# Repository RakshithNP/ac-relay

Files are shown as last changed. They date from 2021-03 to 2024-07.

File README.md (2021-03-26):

View this project on [CADLAB.io](https://cadlab.io/project/24087). 

# AC Relay


It is a relay controlled by an ESP8266 and a push button. It is powered by the main AC.

### Firmwares

#### Test

This firmware allows you to test the hardware if needed. It will change the relay status each 400 millisenconds when the button is pressed and it will send the push button status via serial communication.

#### AdafruitIO

This firmware is based in the Adafruit example for comumnicate with its MQTT broker called AdafruitIO. You can see more in <a href="https://io.adafruit.com">io.adafruit.com</a>

In order to use it you should set:

- Your WiFi setting
- You Adafruit user name
- API Key from Adafruit IO
- The MQTT feed which will be used in Adafruit IO

#### MQTT

This firmware allows you to communicate with a MQTT broker. For example, you can install your own MQTT broker in a Raspberry Pi.

This is the actual firmware that I am using at home with this circuit, and it is prepared for being working 24/7. It does:

- Recovery after a power failure.
- Wake up message
- Reconnect message
- Serial debug
- WiFi reconnect if the signal is lost
- MQTT Broker reconnect if the signal is lost

### For future revisions

- `LED`: LED as IO instead of Power LED
- `ESP8266`: ESP8266 as SoC instead of the ESP8266-12E module
- `UPS`: Uninterrupted Power System. Cesar Fernández idea
- `Capacitive button`: A capacitive external button that acts as the push button

***

<br /><span xmlns:dct="http://purl.org/dc/terms/" property="dct:title">Home AC relay</span> by <span xmlns:cc="http://creativecommons.org/ns#" property="cc:attributionName">Enrique Gómez</span> licensed by <a rel="license" href="http://creativecommons.org/licenses/by-sa/4.0/">Creative Commons Attribution-ShareAlike 4.0 International License</a>.<br /><br />

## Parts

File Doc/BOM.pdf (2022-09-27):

# AC Relay – Bill of Materials

Rev.: 4 | Made By: Enrique Gómez erify By: | Date: 27/09/22
Item Designator Description | Ordering code | Suplier | Manufacturer | Footprint Qty. Ordering code 2 | Suplier 2 | Value
1 | U2 | ESP8266 | - | - | - | - | 1 | - | - | -
2 | U3 | Bloque AC/DC | HLK-PM01 | - | Hi-link | | 1 | HLK-PM01 | HLK-PM01 | 5V output
3 | Q1 | Transistor | 512-FDT86246L | Mouser | On Semiconductor | SOT-223-4 | 1 | FDT86246L | On Semiconductor
4 | D1 | Diodo | 512-RGF1B | Mouser | On Semiconductor | DO-214AC | 1 | RGF1B | On Semiconductor | Vf = 1000v; If = 1A
5 | K1 | Relé | 655-1-2071556-1 | Mouser | TE Connectivity | - | 1 | 1-2071556-1 | TE Connectivity
6 | SW1 | Pulsador | 611-PTS647SN70SMTR2L Mouser | C&K | 4,5 x 4,5 mm 1 | C&K | SPST
7 | R1,R2,R3 | Resistencia | 279-CRGP0603F10K | Mouser | TE Connectivity | 0603 | 3 | CRGP0603F10K | TE Connectivity | 10k
8 | D2 | LED verde | 710-150060VS75000 | Mouser | Wurth Electronics | 0603 | 1 | 150060VS75000 | Wurth Electronics | Vf = 2v; If = 20 mA
9 | R4 | Resistencia | 754-RR0816Q-82R5D89R Mouser | Susumu | 0603 | 1 | RR0816Q-82R5-D-89R Susumu | 82,5 Ohm
10 | U1 | | 755-BU33SD5WG-TR | Mouser | ROHM Semiconductor | SOT-23-5 | 1 | BU33SD5WG-TR | | 3,3V
11 | C1, C2 | Condensador | 77-VJ0603G474KXQPBC | Mouser | Vishay | 0603 | 2 | | Vishay | 470nf
12 | J2 | Header pins | - | - | - | - | 1 | - | - | 01 x 06 pin
13 | J1,J3 | Screw Terminal 651-1985920 | Mouser | Phoenix Contact | 2 x 5 mm | 2 | 1985920 | Phoenix Contact | I = 16A; V = 320v

PTS647SN70SMTR2LF
S

Regulador
voltaje

ROHM
Semiconductor VJ0603G474KXQPW1

BC

### Notas

:

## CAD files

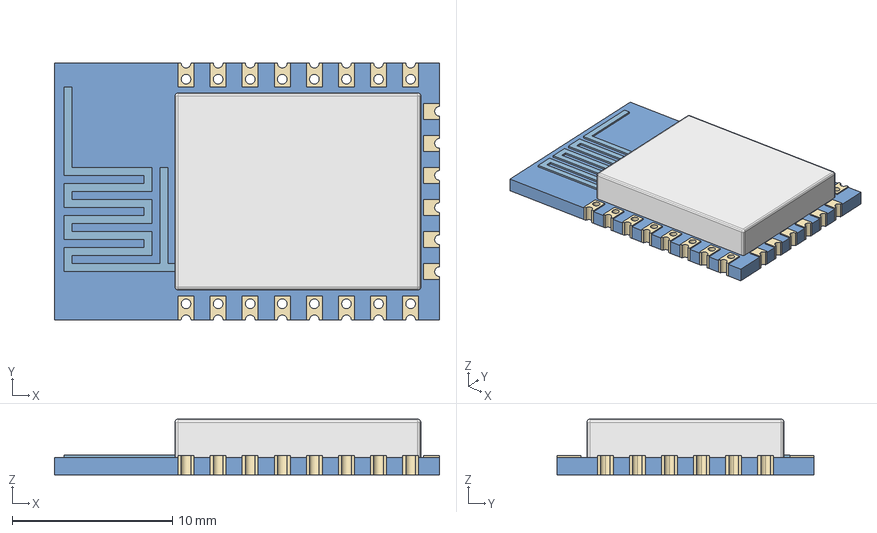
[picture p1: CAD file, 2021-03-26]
KiCad/AC Relay/3dpackages/ESP8266.fcstd
24.0 x 16.0 x 3.48 mm

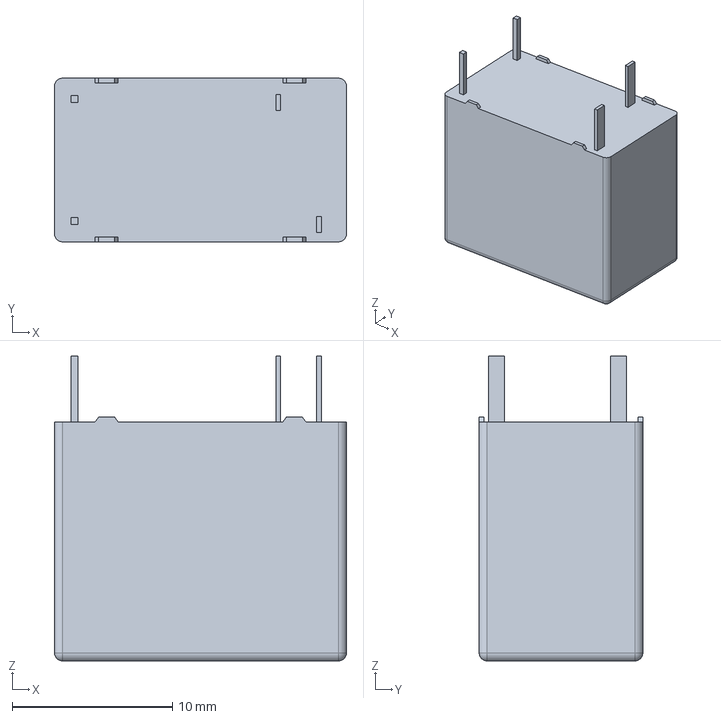
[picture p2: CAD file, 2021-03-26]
KiCad/AC Relay/3dpackages/c-1461492-2-d4-3d.stp
18.2 x 10.2 x 19.0 mm

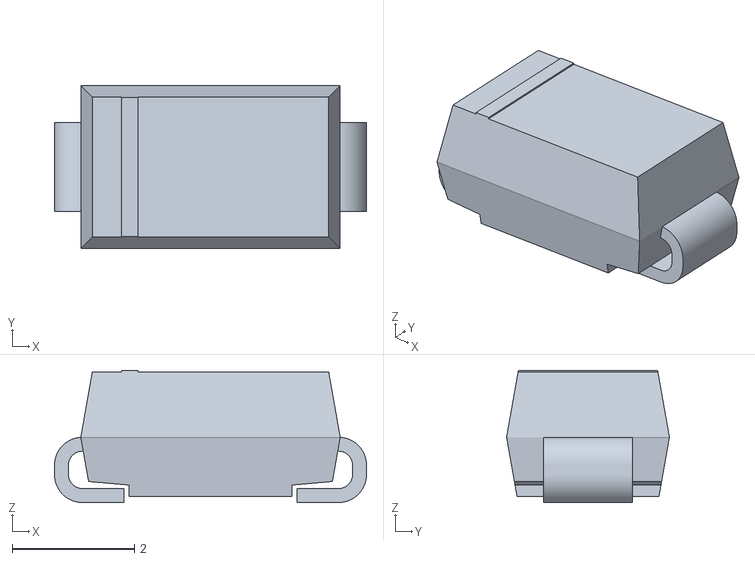
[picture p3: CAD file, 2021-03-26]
KiCad/AC Relay/3dpackages/AB2_DO-214AC_WINGS3D.stl
5.11 x 2.66 x 2.16

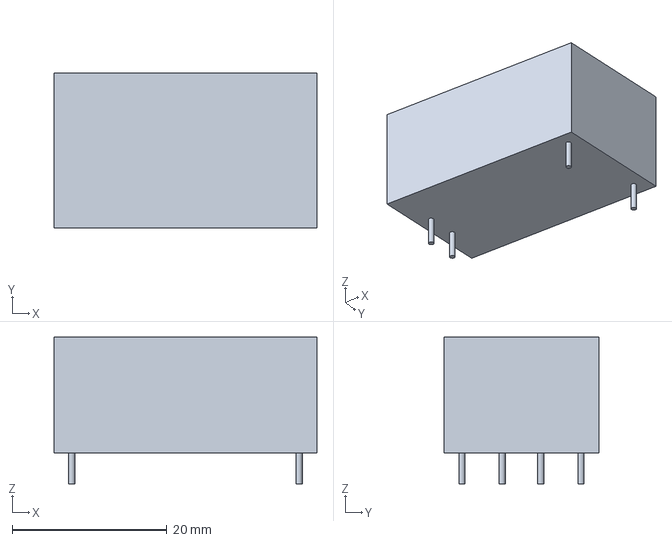
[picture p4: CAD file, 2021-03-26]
KiCad/AC Relay/3dpackages/AC-DC_HLK-PM01.fcstd
34.0 x 20.0 x 19.0 mm

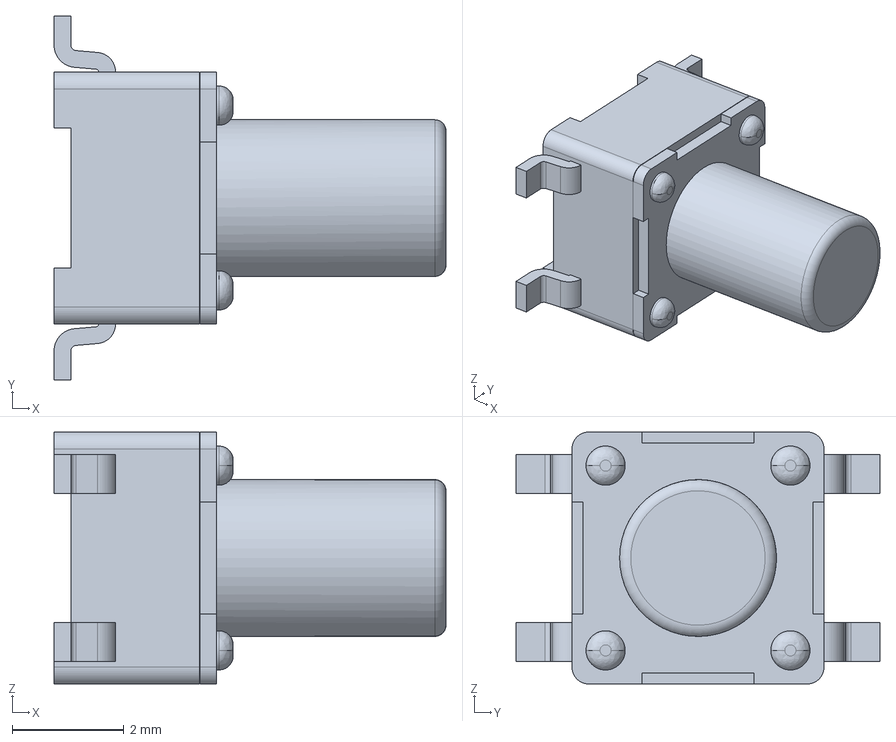
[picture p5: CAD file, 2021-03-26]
KiCad/AC Relay/3dpackages/PTS647SN70SMTR2LFS.stp
7.00 x 6.50 x 4.50 mm

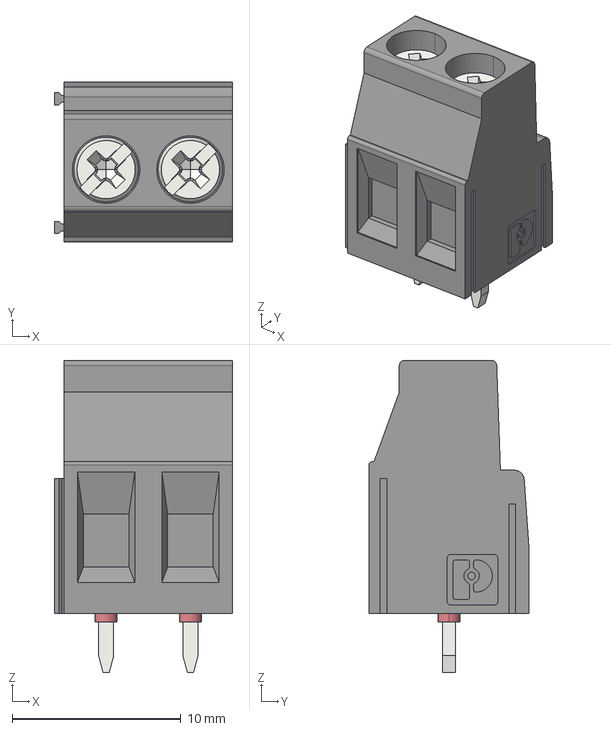
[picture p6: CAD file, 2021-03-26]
KiCad/AC Relay/3dpackages/pxc_1985920_00_MKDSN-2-5-2-HT-BK_3D.stp
10.6 x 9.50 x 18.5 mm
Bohrloch x 2
mkdsn_2.5-2-ht_bk

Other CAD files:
KiCad/AC Relay/3dpackages/ESP8266-12E.stp

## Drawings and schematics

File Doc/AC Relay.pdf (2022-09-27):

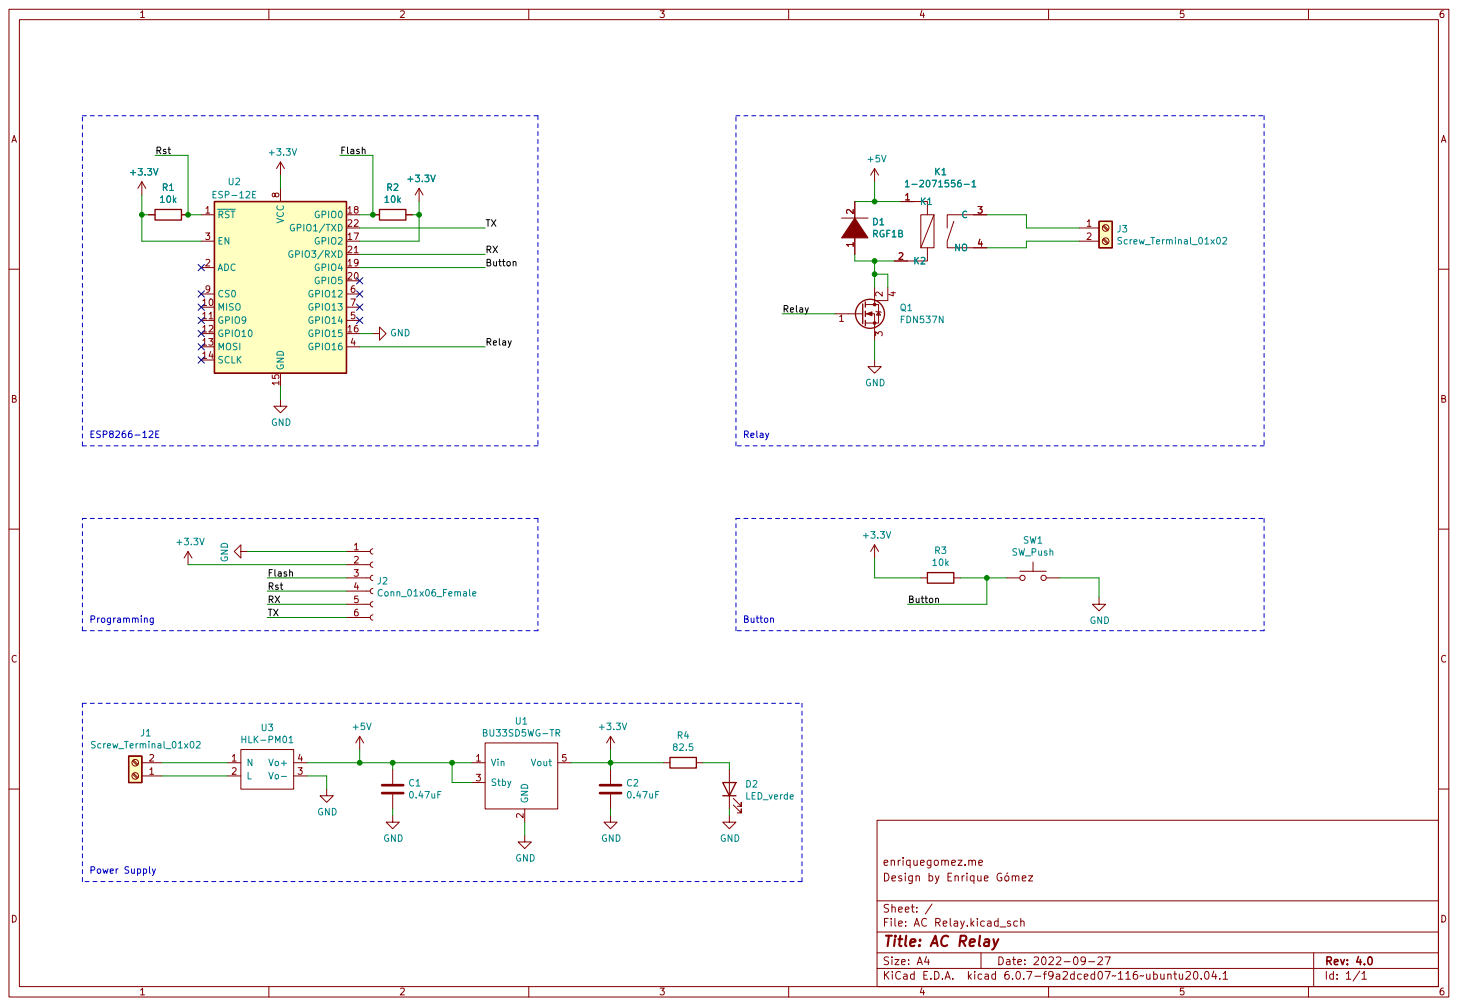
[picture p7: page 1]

enriquegomez.me
File: AC Relay.kicad_sch Sheet: / þÿDesign by Enrique Gómez

Id: 1/1 Title: AC Relay

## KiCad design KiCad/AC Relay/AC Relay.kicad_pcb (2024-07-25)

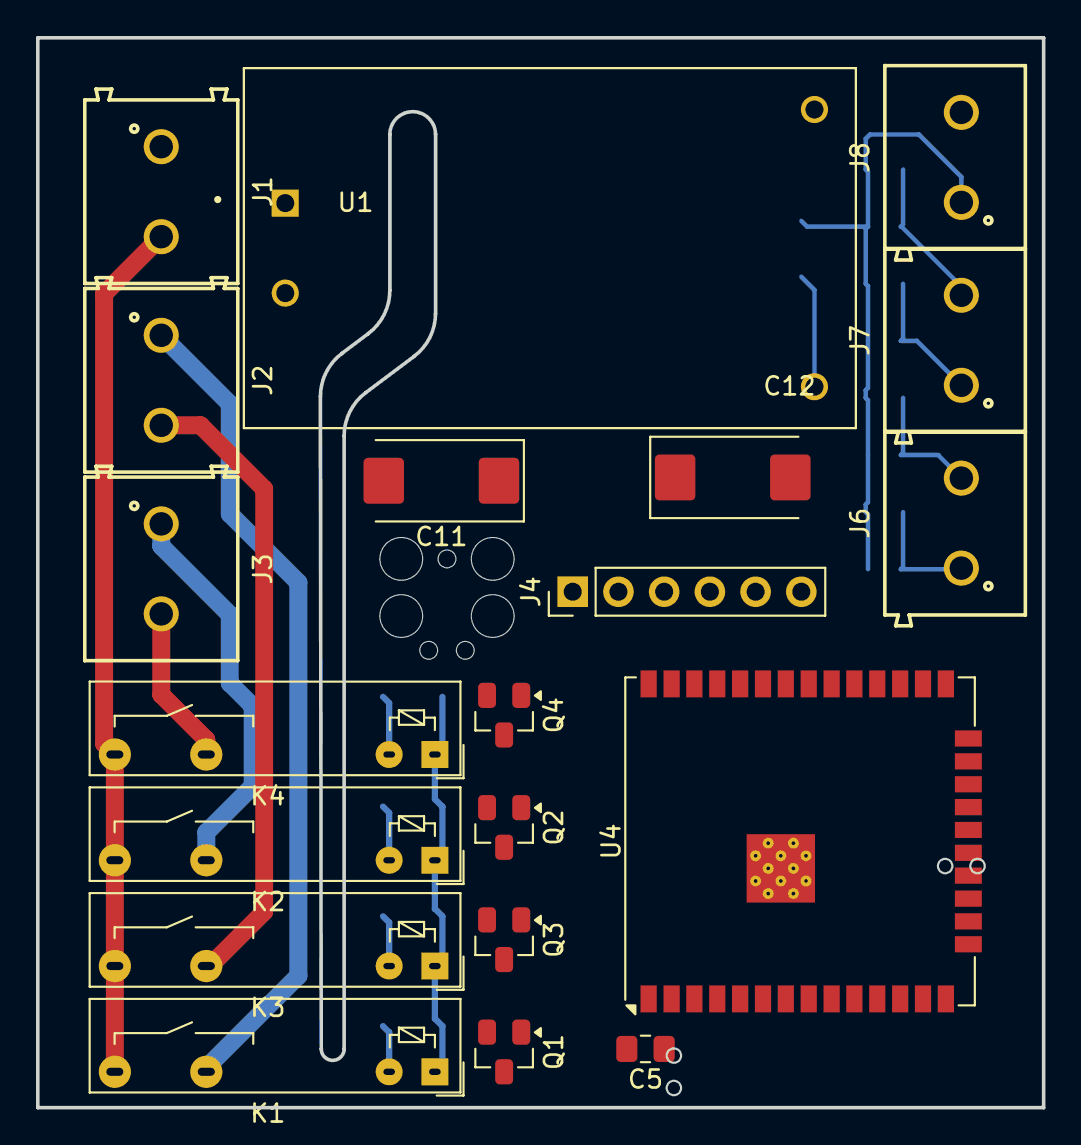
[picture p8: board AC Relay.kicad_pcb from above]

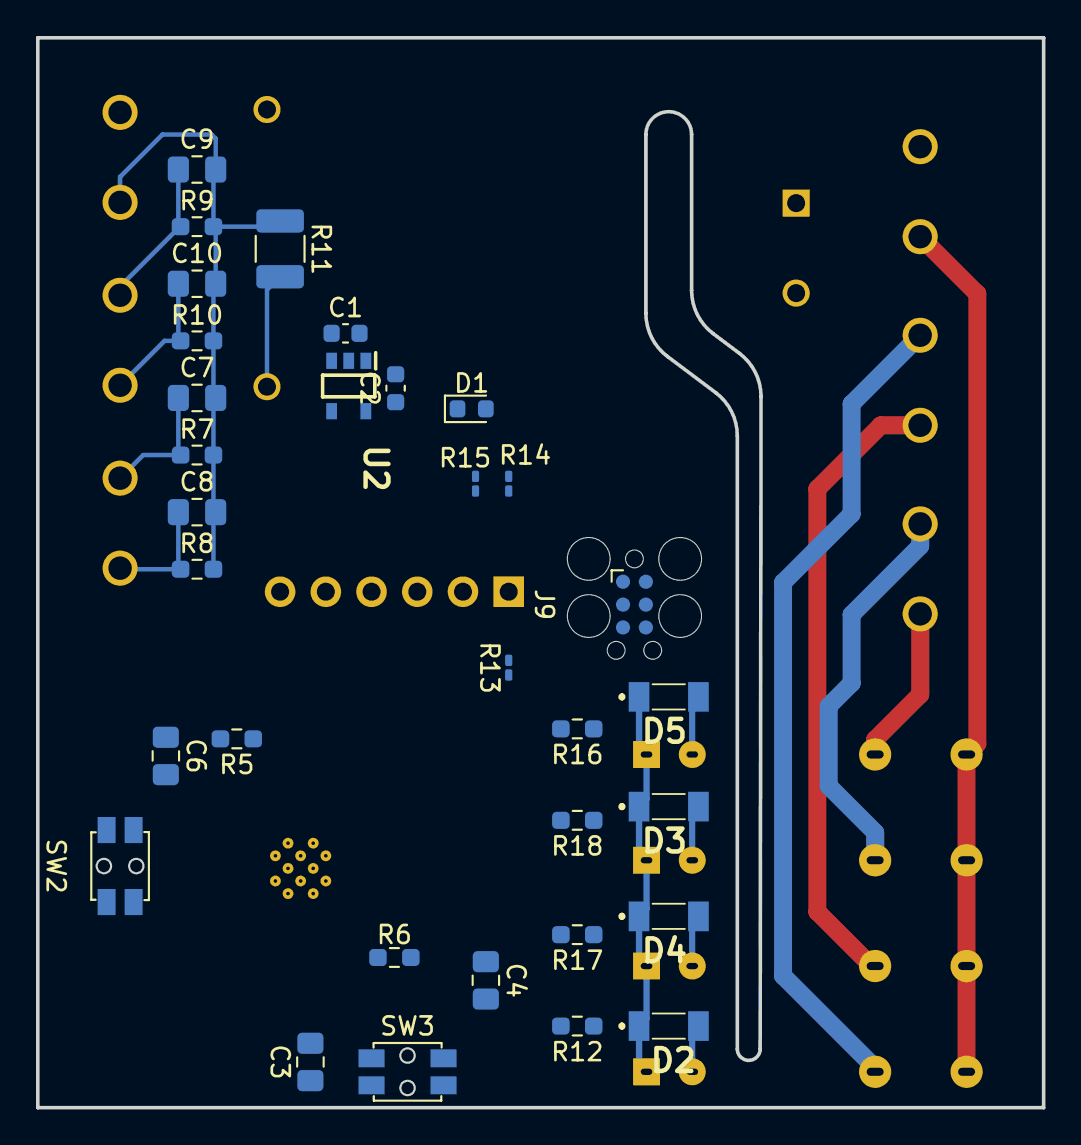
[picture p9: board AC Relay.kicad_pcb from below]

Board: 4 copper layers, 55.9 x 59.4 mm, 52 parts (32 on the bottom side), 32 nets.

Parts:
C1, C2: 1uF; C_0603_1608Metric
C3, C5, C6, C7, C8, C9, C10: 0.1uf; C_0805_2012Metric_Pad1.18x1.45mm_HandSolder
C4: 10uf; C_0805_2012Metric_Pad1.18x1.45mm_HandSolder
C11, C12: 100uF T cap; CP_EIA-7343-20_Kemet-V_Pad2.25x2.55mm_HandSolder
D1: LED_verde; LED_0603_1608Metric
D2, D3, D4, D5: LL4148
J1, J2, J3: Screw_Terminal_01x02; 2_terminal_block
J4: Conn_01x06_Female; PinHeader_1x06_P2.54mm_Vertical
J6, J7, J8: TB002-500-02BE; 2_terminal_block_small
J9: Conn_ARM_SWD_TagConnect_TC2030; Tag-Connect_TC2030-IDC-FP_2x03_P1.27mm_Vertical
K1, K2, K3, K4: 1-2071556-1; Relay_SPST_Fanahar_5A
Q1, Q2, Q3, Q4: FDN537N; SuperSOT-3
R5, R7, R8, R9, R10: 10K; R_0603_1608Metric_Pad0.98x0.95mm_HandSolder
R6: 12K; R_0603_1608Metric_Pad0.98x0.95mm_HandSolder
R11: 330R; R_1210_3225Metric_Pad1.30x2.65mm_HandSolder
R12, R16, R17, R18: 1K; R_0603_1608Metric_Pad0.98x0.95mm_HandSolder
R13, R14: 0R; R_0201_0603Metric_Pad0.64x0.40mm_HandSolder
R15: NA; R_0201_0603Metric_Pad0.64x0.40mm_HandSolder
SW2: Boot; SW_SPST_withpost
SW3: Rst; SW_SPST_withpost
U1: HLK-PM01; CONV_HLK-PM01
U2: BU33SD5WG-TR; SOT95P280X125-5N
U4: ESP32-WROOM-32UE

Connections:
+3V3: C2.1, C4.1, C5.1, C12.1, J4.6, R5.1, R6.1, R15.1, U2.5 (VOUT), U4.2 (VDD)
+5V: C1.1, C11.1, D2.1 (K), D3.1 (K), D4.1 (K), D5.1 (K), K1.K1, K2.K1, K3.K1, K4.K1, R11.2, R14.1, U1.4 (+VO), U2.1 (VIN), U2.3 (STBY)
/AC to DC conv/Neutral: J1.1, U1.1 (AC1)
/AC to DC conv/Phase: J1.2, K1.NO, K2.NO, K3.NO, K4.NO, U1.2 (AC2)
/Relay and diver/Rel_sig1: Q1.1 (G), R12.2
/Relay and diver/Rel_sig2: Q3.1 (G), R17.2
/Relay and diver/Rel_sig3: Q2.1 (G), R18.2
/Relay and diver/Rel_sig4: Q4.1 (G), R16.2
/microcontroller/DTR: C6.1, R5.2, R13.1, SW2.1, SW2.2, U4.25 (IO0)
/microcontroller/RX: J4.2, J9.4 (Rx), U4.35 (TXD0/IO1)
/microcontroller/TX: J4.3, J9.2 (Tx), U4.34 (RXD0/IO3)
/microcontroller/Vcc_sel: J4.4, J9.1 (VCC), R14.2, R15.2
GND: C1.2, C2.2, C3.2, C4.2, C5.2, C6.2, C11.2, C12.2, D1.1 (K), J4.5, J9.5 (GND), Q1.3 (S), Q2.3 (S), Q3.3 (S), Q4.3 (S), SW2.3 (K), SW2.4 (A), SW3.1, SW3.2, U1.3 (-VO), U2.2 (GND), U4.1 (GND), U4.15 (GND), U4.38 (GND), U4.39 (GND)
unnamed: C7.1, J6.2, R7.1
unnamed: C8.1, J6.1, R8.1
unnamed: C9.1, J7.2, R9.1
unnamed: C10.1, J7.1, R10.1
unnamed: C7.2, C8.2, C9.2, C10.2, J8.1, R7.2, R8.2, R9.2, R10.2, R11.1
unnamed: D2.2 (A), K1.K2, Q1.2 (D)
unnamed: D3.2 (A), K2.K2, Q2.2 (D)
unnamed: D4.2 (A), K3.K2, Q3.2 (D)
unnamed: D5.2 (A), K4.K2, Q4.2 (D)
unnamed: J2.1, K1.Com
unnamed: J2.2, K3.Com
unnamed: J3.1, K2.Com
unnamed: J3.2, K4.Com
unnamed: J4.1, R13.2
unnamed: C3.1, R6.2, SW3.3 (K), SW3.4 (A), U4.3 (EN)
unnamed: R12.1, U4.26 (IO4)
unnamed: R16.1, U4.29 (IO5)
unnamed: R17.1, U4.27 (IO16)
unnamed: R18.1, U4.28 (IO17)

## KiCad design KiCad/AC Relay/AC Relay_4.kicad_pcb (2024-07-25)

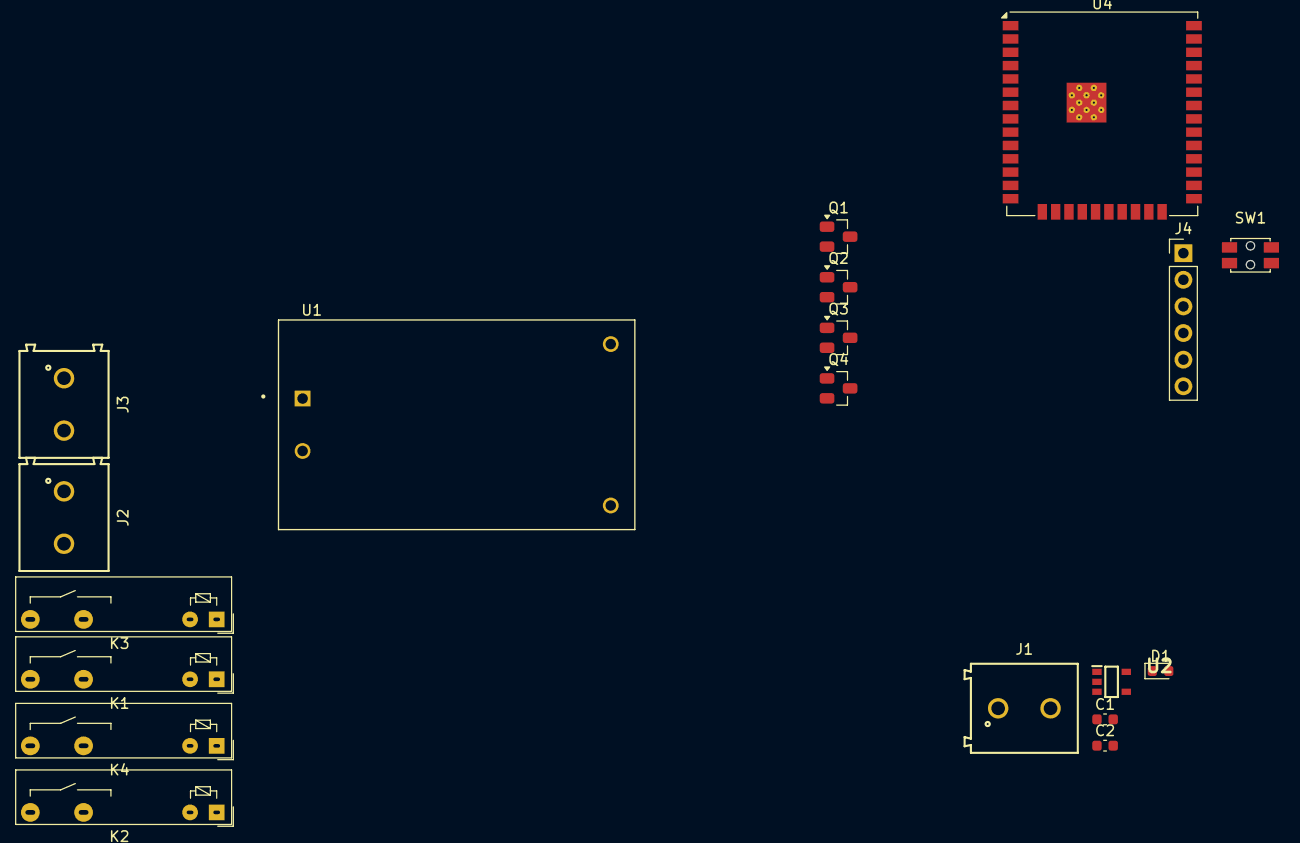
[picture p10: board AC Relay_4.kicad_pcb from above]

Board: 2 copper layers, 19 parts (0 on the bottom side), 14 nets, no tracks yet.

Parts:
C1, C2: 1uF; C_0603_1608Metric
D1: LED_verde; LED_0603_1608Metric
J1, J2, J3: Screw_Terminal_01x02; 2_terminal_block
J4: Conn_01x06_Female; PinHeader_1x06_P2.54mm_Vertical
K1, K2, K3, K4: 1-2071556-1; Relay_SPST_Fanahar_5A
Q1, Q2, Q3, Q4: FDN537N; SuperSOT-3
SW1: SW_Push; SW_SPST_withpost
U1: HLK-PM01; CONV_HLK-PM01
U2: BU33SD5WG-TR; SOT95P280X125-5N
U4: ESP32-WROOM-32UE

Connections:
+3V3: C2.1, J4.2, U2.5 (VOUT)
+5V: C1.1, K1.K1, K2.K1, K3.K1, K4.K1, U1.4 (+VO), U2.1 (VIN), U2.3 (STBY)
/AC to DC conv/Neutral: J1.2, U1.1 (AC1)
/AC to DC conv/Phase: J1.1, K1.NO, K2.NO, K3.NO, K4.NO, U1.2 (AC2)
GND: C1.2, C2.2, D1.1 (K), J4.1, Q1.3 (S), Q2.3 (S), Q3.3 (S), Q4.3 (S), SW1.3 (K), U1.3 (-VO), U2.2 (GND)
unnamed: K1.K2, Q1.2 (D)
unnamed: K2.K2, Q2.2 (D)
unnamed: K3.K2, Q3.2 (D)
unnamed: K4.K2, Q4.2 (D)
unnamed: J2.1, K1.Com
unnamed: J2.2, K3.Com
unnamed: J3.1, K2.Com
unnamed: J3.2, K4.Com
unnamed: U4.1 (GND), U4.15 (GND), U4.38 (GND), U4.39 (GND)

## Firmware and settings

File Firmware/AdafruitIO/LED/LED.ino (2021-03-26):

/***************************************************
  Adafruit MQTT Library ESP8266 Example

  Must use ESP8266 Arduino from:
    https://github.com/esp8266/Arduino

  Works great with Adafruit's Huzzah ESP board & Feather
  ----> https://www.adafruit.com/product/2471
  ----> https://www.adafruit.com/products/2821

  Adafruit invests time and resources providing this open source code,
  please support Adafruit and open-source hardware by purchasing
  products from Adafruit!

  Written by Tony DiCola for Adafruit Industries.
  MIT license, all text above must be included in any redistribution
 ****************************************************/
 /***************************************************
  Edited by Enrique Gómez as example for
  https://github.com/RinconIngenieril/Home-Automation-Devices

  Funcionamiento:
  - Al enviar ON al feed LED de Adafruit IO se apagará el LED
  - Al enviar OFF al feed LED de Adafruit IO se encenderá el LED
 ****************************************************/
#include <ESP8266WiFi.h>
#include "Adafruit_MQTT.h"
#include "Adafruit_MQTT_Client.h"

/************************* WiFi Access Point *********************************/

#define WLAN_SSID       "SSID"
#define WLAN_PASS       "PASSWORD"

/************************* Adafruit.io Setup *********************************/

#define AIO_SERVER      "io.adafruit.com"
#define AIO_SERVERPORT  1883                   // use 8883 for SSL
#define AIO_USERNAME    "nombreDeUsuarioAdafruitIO"
#define AIO_KEY         "tuApiKey"

/************ Global State (you don't need to change this!) ******************/

// Create an ESP8266 WiFiClient class to connect to the MQTT server.
WiFiClient client;

// Setup the MQTT client class by passing in the WiFi client and MQTT server and login details.
Adafruit_MQTT_Client mqtt(&client, AIO_SERVER, AIO_SERVERPORT, AIO_USERNAME, AIO_KEY);

/****************************** Feeds ***************************************/

// Setup a feed called 'onoff' for subscribing to changes.
Adafruit_MQTT_Subscribe onoffrelay = Adafruit_MQTT_Subscribe(&mqtt, AIO_USERNAME "/feeds/LED");

/*************************** Sketch Code ************************************/

void MQTT_connect();

void setup() {
  Serial.begin(115200);
  delay(10);

  pinMode(D0, OUTPUT);
  digitalWrite(D0, LOW);
  pinMode(D4, INPUT);


  /***************** Boot info **************************/
  Serial.println(F("Adafruit MQTT demo"));
  // Connect to WiFi access point.
  Serial.println(); Serial.println();
  Serial.print("Connecting to ");
  Serial.println(WLAN_SSID);
  WiFi.begin(WLAN_SSID, WLAN_PASS);
  while (WiFi.status() != WL_CONNECTED) {
    delay(500);
    Serial.print(".");
  }
  Serial.println();
  Serial.println("WiFi connected");
  Serial.println("IP address: "); Serial.println(WiFi.localIP());



  // Setup MQTT subscription for onoff feed.
  mqtt.subscribe(&onoffrelay);
}

void loop() {
  MQTT_connect();

  if (digitalRead(D2) == LOW){
      digitalWrite(D0, !digitalRead(D0));
      delay(200);
      Serial.println("Pulsado");
    }

  Adafruit_MQTT_Subscribe *subscription;
  while ((subscription = mqtt.readSubscription(1000))) {
    if (subscription == &onoffrelay) {
      Serial.print(F("Got: "));
      Serial.println(((char *)onoffrelay.lastread));

      if (strcmp((char *)onoffrelay.lastread, "ON") == 0){
        digitalWrite(D0, HIGH);
      } else {
        digitalWrite(D0, LOW);
      }
    }
  }


}

// Function to connect and reconnect as necessary to the MQTT server.
void MQTT_connect() {
  int8_t ret;

  // Stop if already connected.
  if (mqtt.connected()) {
    return;
  }

  Serial.print("Connecting to MQTT... ");

  uint8_t retries = 3;
  while ((ret = mqtt.connect()) != 0) { // connect will return 0 for connected
       Serial.println(mqtt.connectErrorString(ret));
       Serial.println("Retrying MQTT connection in 5 seconds...");
       mqtt.disconnect();
       delay(5000);  // wait 5 seconds
       retries--;
       if (retries == 0) {
         // basically die and wait for WDT to reset me
         while (1);
       }
  }
  Serial.println("MQTT Connected!");
}

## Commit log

2021-03-26 kick off
    [AB2_DO-214AC_WINGS3D.stl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]
2021-03-26 Silk screen and bigger solder surface
    [AC Relay.kicad_pcb]
2021-03-26 update gerbers and docs
    [AC Relay-B.Cu.gbl, AC Relay-B.Mask.gbs, AC Relay-B.SilkS.gbo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]
2022-09-27 rev: 4 - Change relay to 16 A
    [AC Relay.kicad_pcb, AC Relay.kicad_sch, BOM.ods]
2022-10-29 Change diameter of hole
2022-10-29 Change diode footprint
    [AC Relay.kicad_pcb]
2022-10-29 Update gerbers
    [AC Relay-B_Cu.gbl, AC Relay-B_Mask.gbs, AC Relay-B_Silkscreen.gbo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]
2024-05-30 initial commit
    this is the intitial commit
    [AC Relay.kicad_sch]
2024-07-22 title edited
    [AC Relay.kicad_pcb, AC Relay.kicad_sch]
2024-07-25 until components placemaent
    done all until com placement, but had isssue in edge cut .
    [AC Relay.kicad_pcb, AC Relay.kicad_sch, AC Relay_4.kicad_pcb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]
2024-07-25 added cutout
    added cutout at the ac and dc isolatin part
    [AC Relay.kicad_pcb]
2024-07-25 error elemination
    schametic error elemination
    [AC Relay.kicad_pcb, AC Relay.kicad_sch, AC-DC.kicad_sch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]
